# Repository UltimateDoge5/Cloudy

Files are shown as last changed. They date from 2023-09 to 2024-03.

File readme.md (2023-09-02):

# Cloudy

A weather station with a fronted UI and PHP backend was my first-ever web project. It has been 4 years since I finished it, and I've decided to do it again but with my current knowledge.

Another reason for this project is that I wanted to learn how to design schematics and PCBs.
You can see the (hopefully) live data on the [website](https://cloudy.pkozak.org).

## Hardware

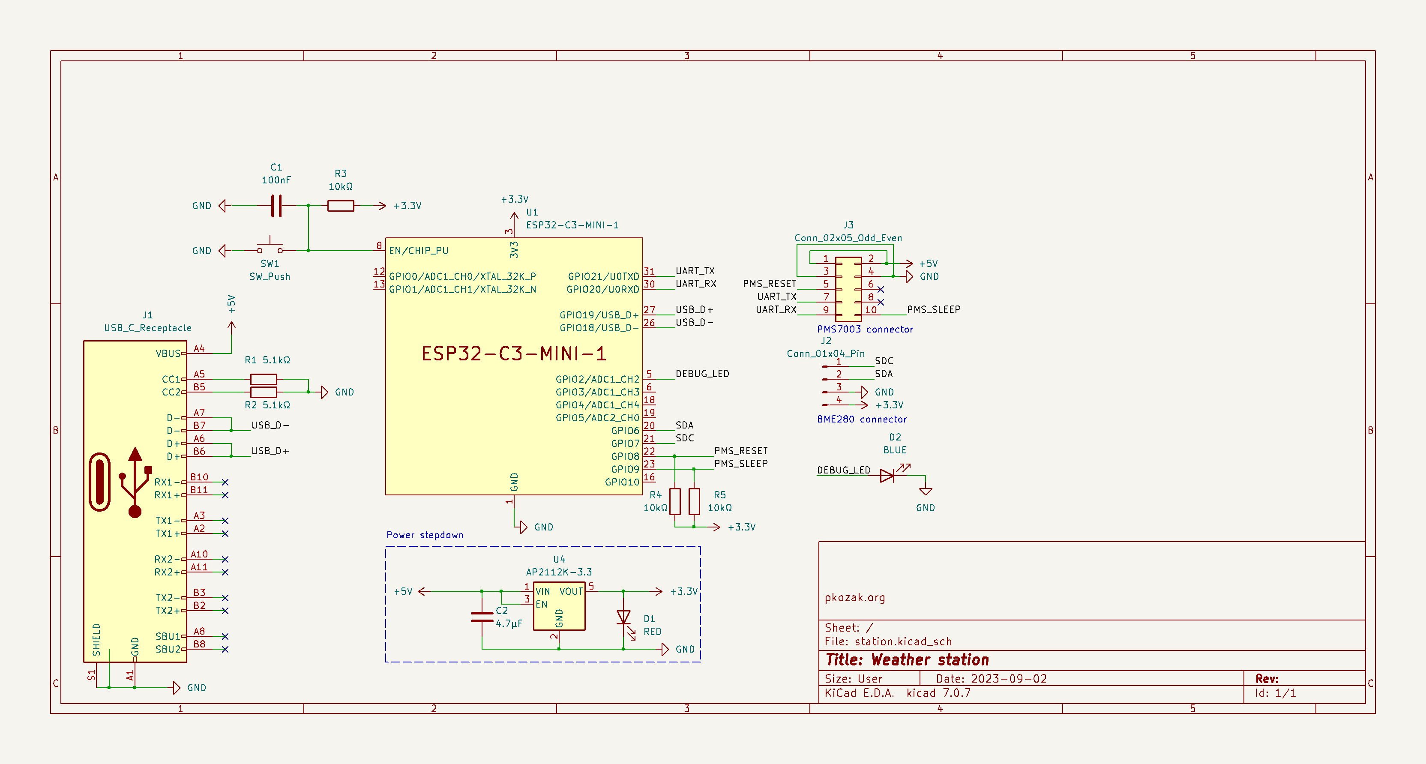
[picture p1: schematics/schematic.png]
Schematic of the weather station


The station uses a BME280 sensor to measure temperature, humidity and pressure. Besides uploading the data, it's also shown on a 0.96" OLED display (Not included in schematic).

The [schematics](/schematics/) and PCB use an ESP32-C3-MINI-N4, but because of the costs of manufacturing, assembly/stencil and
shipping, I've decided to assemble it on a breadboard with an ESP32-WROOM devkit.

The [schematics](/schematics/) also include a 3.3V voltage regulator, USB type C for power and programming, and a IDC header for a PMS7003 air quality sensor that I could integrate later if I'd like to.

As for the future sensors, aside from the PM2.5 sensor, I'd like to add a rain sensor and an anemometer.
The first one is cheap and easy to do, but the second one is not so much. Anemometers are expensive, and I don't have the tools to make one myself.
Even if I had one, I do not have an appropriate location to install it.

## Software

The software for the station is in the [driver folder](./driver). It's written in C++ and uses Arduino libraries. For the backend, I've decided to use Supabase, because of the REST database API and the real-time features which allowed an easy integration with the microcontroller.

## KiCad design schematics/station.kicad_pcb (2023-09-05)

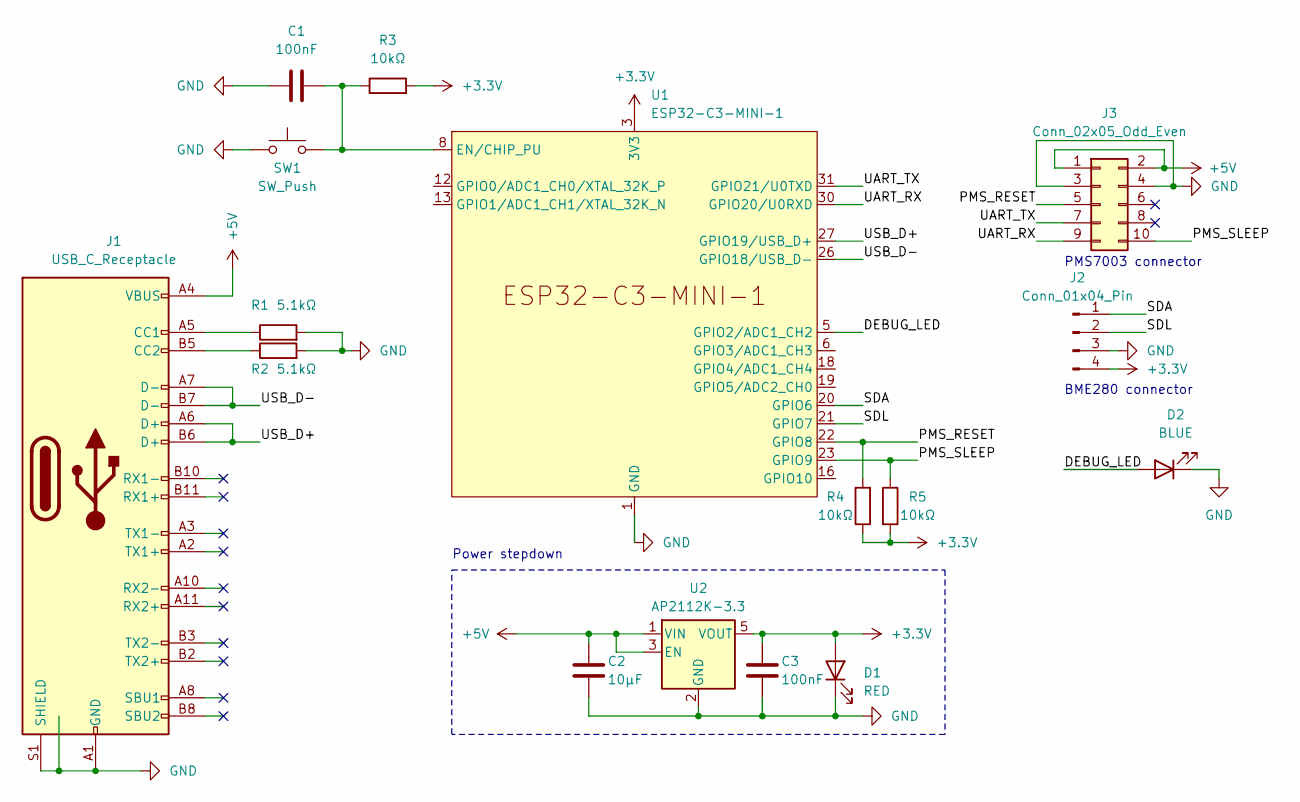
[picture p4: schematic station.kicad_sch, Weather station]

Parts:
C1, C3: 100nF; C_0805_2012Metric_Pad1.18x1.45mm_HandSolder
C2: 10µF; C_0805_2012Metric_Pad1.18x1.45mm_HandSolder
D1: RED; LED_0805_2012Metric_Pad1.15x1.40mm_HandSolder
D2: BLUE; LED_0805_2012Metric_Pad1.15x1.40mm_HandSolder
J1: USB_C_Receptacle; USB_C_Receptacle_Amphenol_12401610E4-2A
J2: Conn_01x04_Pin; PinHeader_1x04_P2.54mm_Vertical
J3: Conn_02x05_Odd_Even; IDC-Header_2x05_P2.54mm_Vertical
R1, R2: 5.1kΩ; R_1206_3216Metric
R3, R4, R5: 10kΩ; R_1206_3216Metric
SW1: SW_Push; SW_PUSH_6mm_H5mm
U1: ESP32-C3-MINI-1
U2: AP2112K-3.3; SOT-23-5

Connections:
+3.3V: C3.1, D1.2 (A), J2.4, R3.2, R4.1, R5.2, U1.3 (3V3), U2.5 (VOUT)
+5V: C2.1, J1.A4 (VBUS), J1.A9 (VBUS), J1.B4 (VBUS), J1.B9 (VBUS), J3.1, J3.2, U2.1 (VIN), U2.3 (EN)
/DEBUG_LED: D2.2 (A), U1.5 (GPIO2/ADC1_CH2)
/PMS_RESET: J3.5, R4.2, U1.22 (GPIO8)
/PMS_SLEEP: J3.10, R5.1, U1.23 (GPIO9)
/SDA: J2.1, U1.20 (GPIO6)
/SDL: J2.2, U1.21 (GPIO7)
/UART_RX: J3.9, U1.30 (GPIO20/U0RXD)
/UART_TX: J3.7, U1.31 (GPIO21/U0TXD)
/USB_D+: J1.A6 (D+), J1.B6 (D+), U1.27 (GPIO19/USB_D+)
/USB_D-: J1.A7 (D-), J1.B7 (D-), U1.26 (GPIO18/USB_D-)
GND: C1.1, C2.2, C3.2, D1.1 (K), D2.1 (K), J1.A1 (GND), J1.A12 (GND), J1.B1 (GND), J1.B12 (GND), J1.S1 (SHIELD), J2.3, J3.3, J3.4, R1.2, R2.2, SW1.1, U1.1 (GND), U1.2 (GND), U1.11 (GND), U1.14 (GND), U1.36 (GND), U1.37 (GND), U1.38 (GND), U1.39 (GND), U1.40 (GND), U1.41 (GND), U1.42 (GND), U1.43 (GND), U1.44 (GND), U1.45 (GND), U1.46 (GND), U1.47 (GND), U1.48 (GND), U1.49 (GND), U1.50 (GND), U1.51 (GND), U1.52 (GND), U1.53 (GND), U2.2 (GND)
unnamed: J1.A5 (CC1), R1.1
unnamed: J1.B5 (CC2), R2.1
unnamed: C1.2, R3.1, SW1.2, U1.8 (EN/CHIP_PU)

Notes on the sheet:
BME280 connector
Power stepdown
PMS7003 connector

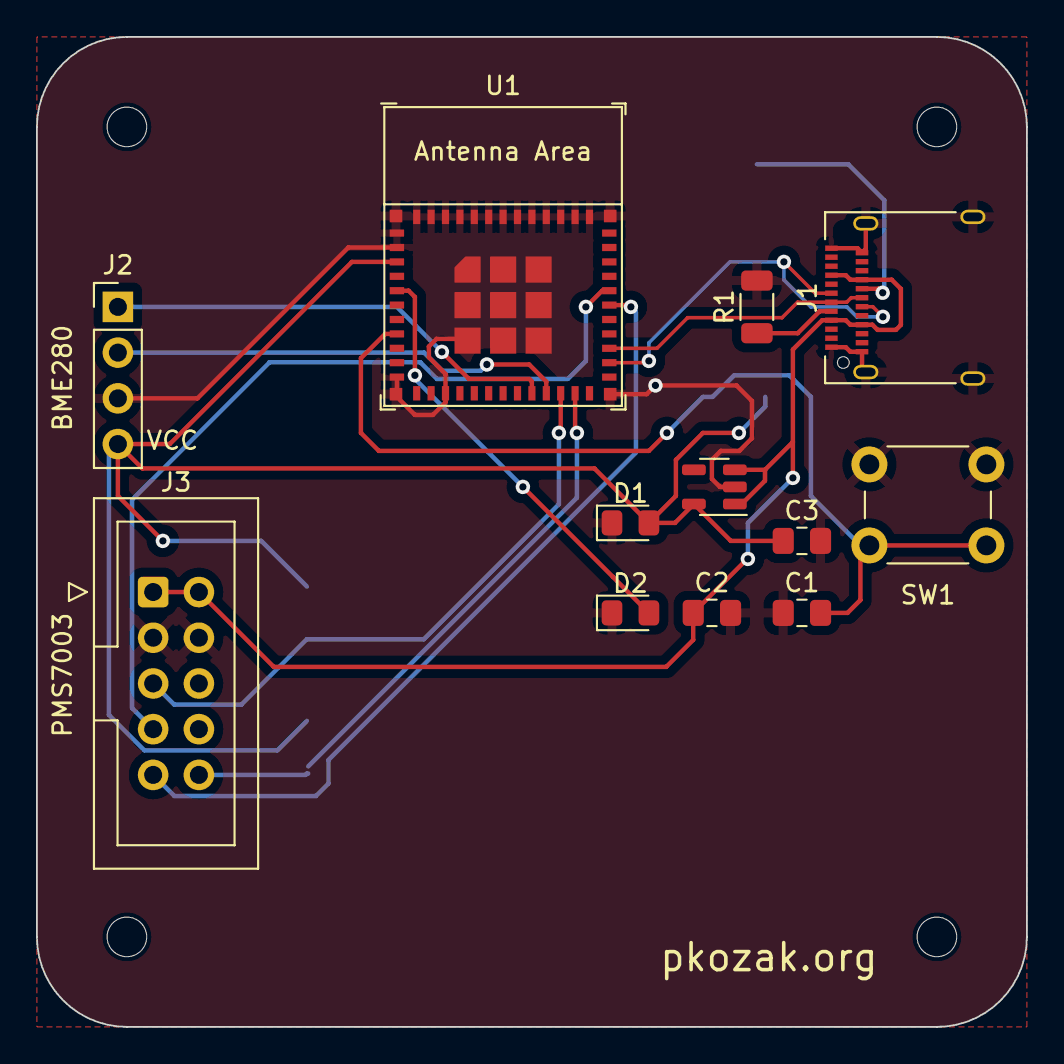
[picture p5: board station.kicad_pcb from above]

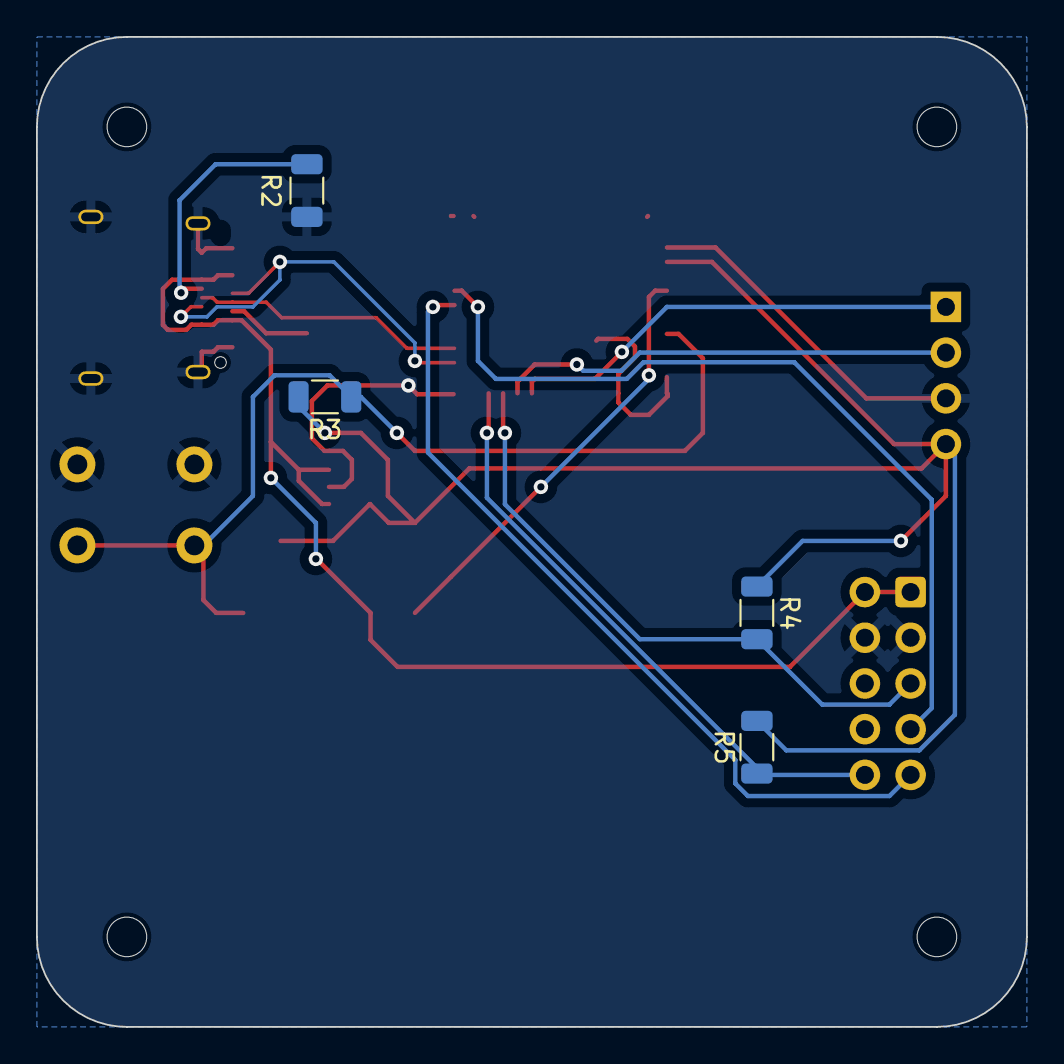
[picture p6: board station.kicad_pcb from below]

Board: 2 copper layers, 55.0 x 55.0 mm, 16 parts (4 on the bottom side), 15 nets.

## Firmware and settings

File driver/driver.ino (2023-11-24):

#include "time.h"
#include <Wire.h>
#include <WiFi.h>
#include <WiFiClientSecure.h>
#include <HTTPClient.h>
#include <Arduino_JSON.h>
#include <Adafruit_Sensor.h>
#include <Adafruit_BME280.h>
#include <Adafruit_GFX.h>
#include <Adafruit_SH110X.h>
#include <EEPROM.h>
#include "logo.h"
// Contains the WiFi credentials and the Supabase URL and key
#include "envs.h"

#define I2C_SDA 21
#define I2C_SCL 22
#define WAKEUP_PIN 4

#define i2c_Address 0x3c

#define SCREEN_WIDTH 128 // OLED display width, in pixels
#define SCREEN_HEIGHT 64 // OLED display height, in pixels
#define OLED_RESET 19

// Time between uploads to the database
#define DATABASE_INTERVAL 20000
#define SEALEVELPRESSURE_HPA (1013.25)

#define DEBUG_LED true  // Set to true to enable the debug LED
#define DEBUG_LED_PIN 2 // Onboard LED of the ESP32 dev board

#define INTEGER_LIMIT 2147483647

const char *ntpServer = "pool.ntp.org";
const long gmtOffset_sec = 3600;
const int daylightOffset_sec = 3600;

TaskHandle_t UploadTask;

TwoWire I2CWire = TwoWire(0);
Adafruit_SH1106G display = Adafruit_SH1106G(SCREEN_WIDTH, SCREEN_HEIGHT, &I2CWire, OLED_RESET);
Adafruit_BME280 bme;

String uploadError = "";

int screenTime = 0;

void setup()
{
  pinMode(WAKEUP_PIN, INPUT);
  pinMode(DEBUG_LED_PIN, OUTPUT);

  Serial.begin(115200);
  I2CWire.begin(I2C_SDA, I2C_SCL, 100000);

  delay(250);
  display.begin(i2c_Address, true);
  display.setTextSize(1);
  display.setTextColor(SH110X_WHITE);
  display.setCursor(0, 0);
  display.clearDisplay();
  display.drawBitmap((SCREEN_WIDTH - 32) / 2, (SCREEN_HEIGHT - 32) / 2, logo, 32, 32, SH110X_WHITE);
  display.setCursor((SCREEN_WIDTH - 32) / 2 - 16, (SCREEN_HEIGHT - 32) / 2 + 38);
  display.println("pkozak.org");
  display.display();
  delay(350);

  bool status = bme.begin(0x76, &I2CWire);
  if (!status)
  {
    Serial.println("Could not find the BME280 sensor!");
#ifdef DEBUG_LED
    digitalWrite(DEBUG_LED_PIN, HIGH);
#endif
    while (1)
    {
      display.clearDisplay();
      display.setCursor(0, 0);
      display.setTextSize(2);
      display.invertDisplay(false);
      display.println("No sensor!");
      display.setTextSize(1);
      display.println("No BME280 sensor.");
      display.println("Please check the wiring");
      display.display();
      delay(1500);
      display.clearDisplay();
      display.setCursor(0, 0);
      display.setTextSize(2);
      display.invertDisplay(true);
      display.println("No sensor!");
      display.setTextSize(1);
      display.println("No BME280 sensor.");
      display.println("Please check the wiring");
      display.display();
      delay(1500);
    }
  }

  EEPROM.writeInt(0x00, 0);
  EEPROM.commit();

  WiFi.begin(ssid, password);
  Serial.print("Connecting...");

  display.clearDisplay();
  display.setCursor(0, 0);
  display.println("Connecting to WiFi");
  display.display();

  while (WiFi.status() != WL_CONNECTED && WiFi.status() != WL_CONNECT_FAILED)
  {
    delay(500);
    Serial.print(".");
    display.print(".");
    display.display();
  }

  display.clearDisplay();
  display.setCursor(0, 0);
  if (WiFi.status() != WL_CONNECT_FAILED)
  {
    configTime(gmtOffset_sec, daylightOffset_sec, ntpServer);
    Serial.println("");
    Serial.print("Connected to WiFi\n");

    display.println("Connected to WiFi");
    display.display();

    xTaskCreatePinnedToCore(
        UploadData,   /* Task function. */
        "uploadData", /* name of task. */
        10000,        /* Stack size of task */
        NULL,         /* parameter of the task */
        1,            /* priority of the task */
        &UploadTask,  /* Task handle to keep track of created task */
        1);           /* pin task to core 1 */
  }
  else
  {
    Serial.println("");
    Serial.println("Connection failed\n");
    Serial.println("Working in offline mode");

    display.println("Connection failed");
    display.println("Working in offline mode");
    display.display();
  }
}

void loop()
{
  // After 10s of inactivity, display the screen saver
  if (screenTime >= 10000)
  {
    display.clearDisplay();
    while (digitalRead(WAKEUP_PIN) == LOW)
    {
      // Clear the screen and wait for the button to be pressed
    }
    screenTime = 0;
  }

  struct tm timeinfo;
  getLocalTime(&timeinfo);

  int temp = bme.readTemperature();
  int pressure = bme.readPressure() / 100.0F;
  int humidity = bme.readHumidity();

  display.clearDisplay();
  display.setCursor(0, 0);
  if (temp == INTEGER_LIMIT || pressure < 0) // Avoid displaying invalid data
  {
    display.setTextSize(2);
    display.println("Error while reading data");
    display.setTextSize(1);
    display.println("Please restart");
#ifdef DEBUG_LED
    digitalWrite(DEBUG_LED_PIN, HIGH);
#endif
  }
  else
  {
    display.println("Temp: " + String(temp) + " C");
    display.println("Pressure: " + String(pressure) + " hPa");
    display.println("Humidity: " + String(humidity) + "%");
    screenTime += 500;
  }

  if (WiFi.status() == WL_CONNECTED)
  {
    display.println("");
    display.println(&timeinfo, "%H:%M:%S");
  }
  else
  {
    display.setCursor(0, SCREEN_HEIGHT - 10);
    display.println("Offline");
  }

  if (uploadError != "")
  {
    display.setCursor(0, SCREEN_HEIGHT - 10);
    display.println(uploadError);
  }

  display.drawBitmap(SCREEN_WIDTH - 32, SCREEN_HEIGHT - 32, logo, 32, 32, SH110X_WHITE);
  display.display();

  delay(500);
}

void UploadData(void *pvParameters)
{
  while (1)
  {
    int time = millis();
    float temp = bme.readTemperature();
    int pressure = bme.readPressure() / 100.0F;
    if (temp == INTEGER_LIMIT || pressure < 0) // Avoid uploading invalid data
    {
      Serial.println("Error while reading data, skipping upload");
#ifdef DEBUG_LED
      digitalWrite(DEBUG_LED_PIN, HIGH);
#endif
      delay(DATABASE_INTERVAL);
      return;

      // Read restart count from eeprom
      int restarts = EEPROM.read(0x00);
      if (restarts == 3)
      {
        return;
      }

      EEPROM.writeInt(0x00, restarts + 1);
      EEPROM.commit();
      ESP.restart();
    }

    HTTPClient http;
    http.begin(SUPABASE_URL);
    http.addHeader("Content-Type", "application/json");
    http.addHeader("Authorization", String("Bearer ") + String(SUPABASE_KEY));
    http.addHeader("apikey", String(SUPABASE_KEY));

    JSONVar weather;

    weather["temperature"] = bme.readTemperature();
    weather["pressure"] = bme.readPressure() / 100.0F;
    weather["humidity"] = bme.readHumidity();

    int resp = http.POST(JSON.stringify(weather));
    if (resp != 201)
    {
      Serial.println("Error uploading data");
      Serial.println(http.errorToString(resp));
      Serial.println(http.getString());
      uploadError = "Error code " + String(resp);
#ifdef DEBUG_LED
      digitalWrite(DEBUG_LED_PIN, HIGH);
#endif
    }
    else
    {
      uploadError = "";
#ifdef DEBUG_LED
      digitalWrite(DEBUG_LED_PIN, LOW);
#endif
    }

    int diff = millis() - time;
    delay(DATABASE_INTERVAL - diff);
  }
}

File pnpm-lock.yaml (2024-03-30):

lockfileVersion: '6.0'

settings:
  autoInstallPeers: true
  excludeLinksFromLockfile: false

dependencies:
  '@headlessui/react':
    specifier: ^1.7.18
    version: 1.7.18(react-dom@18.2.0)(react@18.2.0)
  '@supabase/supabase-js':
    specifier: ^2.41.1
    version: 2.41.1
  '@types/node':
    specifier: 20.12.2
    version: 20.12.2
  '@types/react':
    specifier: 18.2.73
    version: 18.2.73
  '@types/react-dom':
    specifier: 18.2.23
    version: 18.2.23
  chart.js:
    specifier: ^4.4.2
    version: 4.4.2
  chartjs-adapter-dayjs-4:
    specifier: ^1.0.4
    version: 1.0.4(chart.js@4.4.2)(dayjs@1.11.10)
  dayjs:
    specifier: ^1.11.10
    version: 1.11.10
  eslint:
    specifier: 8.57.0
    version: 8.57.0
  eslint-config-next:
    specifier: 14.1.4
    version: 14.1.4(eslint@8.57.0)(typescript@5.4.3)
  next:
    specifier: 14.1.4
    version: 14.1.4(react-dom@18.2.0)(react@18.2.0)
  react:
    specifier: 18.2.0
    version: 18.2.0
  react-chartjs-2:
    specifier: ^5.2.0
    version: 5.2.0(chart.js@4.4.2)(react@18.2.0)
  react-dom:
    specifier: 18.2.0
    version: 18.2.0(react@18.2.0)
  typescript:
    specifier: 5.4.3
    version: 5.4.3

devDependencies:
  '@typescript-eslint/eslint-plugin':
    specifier: ^6.11.0
    version: 6.11.0(@typescript-eslint/parser@6.11.0)(eslint@8.57.0)(typescript@5.4.3)
  '@typescript-eslint/parser':
    specifier: ^6.11.0
    version: 6.11.0(eslint@8.57.0)(typescript@5.4.3)
  autoprefixer:
    specifier: ^10.4.19
    version: 10.4.19(postcss@8.4.38)
  postcss:
    specifier: ^8.4.38
    version: 8.4.38
  prettier:
    specifier: ^3.2.5
    version: 3.2.5
  prettier-plugin-tailwindcss:
    specifier: ^0.5.13
    version: 0.5.13(prettier@3.2.5)
  tailwindcss:
    specifier: ^3.4.3
    version: 3.4.3

packages:

  /@aashutoshrathi/word-wrap@1.2.6:
    resolution: {integrity: sha512-1Yjs2SvM8TflER/OD3cOjhWWOZb58A2t7wpE2S9XfBYTiIl+XFhQG2bjy4Pu1I+EAlCNUzRDYDdFwFYUKvXcIA==}
    engines: {node: '>=0.10.0'}

  /@alloc/quick-lru@5.2.0:
    resolution: {integrity: sha512-UrcABB+4bUrFABwbluTIBErXwvbsU/V7TZWfmbgJfbkwiBuziS9gxdODUyuiecfdGQ85jglMW6juS3+z5TsKLw==}
    engines: {node: '>=10'}
    dev: true

  /@babel/runtime@7.24.1:
    resolution: {integrity: sha512-+BIznRzyqBf+2wCTxcKE3wDjfGeCoVE61KSHGpkzqrLi8qxqFwBeUFyId2cxkTmm55fzDGnm0+yCxaxygrLUnQ==}
    engines: {node: '>=6.9.0'}
    dependencies:
      regenerator-runtime: 0.14.1
    dev: false

  /@eslint-community/eslint-utils@4.4.0(eslint@8.57.0):
    resolution: {integrity: sha512-1/sA4dwrzBAyeUoQ6oxahHKmrZvsnLCg4RfxW3ZFGGmQkSNQPFNLV9CUEFQP1x9EYXHTo5p6xdhZM1Ne9p/AfA==}
    engines: {node: ^12.22.0 || ^14.17.0 || >=16.0.0}
    peerDependencies:
      eslint: ^6.0.0 || ^7.0.0 || >=8.0.0
    dependencies:
      eslint: 8.57.0
      eslint-visitor-keys: 3.4.3

  /@eslint-community/regexpp@4.10.0:
    resolution: {integrity: sha512-Cu96Sd2By9mCNTx2iyKOmq10v22jUVQv0lQnlGNy16oE9589yE+QADPbrMGCkA51cKZSg3Pu/aTJVTGfL/qjUA==}
    engines: {node: ^12.0.0 || ^14.0.0 || >=16.0.0}

  /@eslint/eslintrc@2.1.4:
    resolution: {integrity: sha512-269Z39MS6wVJtsoUl10L60WdkhJVdPG24Q4eZTH3nnF6lpvSShEK3wQjDX9JRWAUPvPh7COouPpU9IrqaZFvtQ==}
    engines: {node: ^12.22.0 || ^14.17.0 || >=16.0.0}
    dependencies:
      ajv: 6.12.6
      debug: 4.3.4
      espree: 9.6.1
      globals: 13.24.0
      ignore: 5.3.1
      import-fresh: 3.3.0
      js-yaml: 4.1.0
      minimatch: 3.1.2
      strip-json-comments: 3.1.1
    transitivePeerDependencies:
      - supports-color

  /@eslint/js@8.57.0:
    resolution: {integrity: sha512-Ys+3g2TaW7gADOJzPt83SJtCDhMjndcDMFVQ/Tj9iA1BfJzFKD9mAUXT3OenpuPHbI6P/myECxRJrofUsDx/5g==}
    engines: {node: ^12.22.0 || ^14.17.0 || >=16.0.0}

  /@headlessui/react@1.7.18(react-dom@18.2.0)(react@18.2.0):
    resolution: {integrity: sha512-4i5DOrzwN4qSgNsL4Si61VMkUcWbcSKueUV7sFhpHzQcSShdlHENE5+QBntMSRvHt8NyoFO2AGG8si9lq+w4zQ==}
    engines: {node: '>=10'}
    peerDependencies:
      react: ^16 || ^17 || ^18
      react-dom: ^16 || ^17 || ^18
    dependencies:
      '@tanstack/react-virtual': 3.2.0(react-dom@18.2.0)(react@18.2.0)
      client-only: 0.0.1
      react: 18.2.0
      react-dom: 18.2.0(react@18.2.0)
    dev: false

  /@humanwhocodes/config-array@0.11.14:
    resolution: {integrity: sha512-3T8LkOmg45BV5FICb15QQMsyUSWrQ8AygVfC7ZG32zOalnqrilm018ZVCw0eapXux8FtA33q8PSRSstjee3jSg==}
    engines: {node: '>=10.10.0'}
    dependencies:
      '@humanwhocodes/object-schema': 2.0.2
      debug: 4.3.4
      minimatch: 3.1.2
    transitivePeerDependencies:
      - supports-color

  /@humanwhocodes/module-importer@1.0.1:
    resolution: {integrity: sha512-bxveV4V8v5Yb4ncFTT3rPSgZBOpCkjfK0y4oVVVJwIuDVBRMDXrPyXRL988i5ap9m9bnyEEjWfm5WkBmtffLfA==}
    engines: {node: '>=12.22'}

  /@humanwhocodes/object-schema@2.0.2:
    resolution: {integrity: sha512-6EwiSjwWYP7pTckG6I5eyFANjPhmPjUX9JRLUSfNPC7FX7zK9gyZAfUEaECL6ALTpGX5AjnBq3C9XmVWPitNpw==}
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

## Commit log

2023-08-22 Finished the offline driver
2023-08-22 Driver now uploads data to db
2023-08-22 Added invalid value checks
    Added invalid value checks and a screen saver to prevent burn-in.
    [driver.ino]
2023-08-23 Removed prisma
    Removed prisma and switched to pnpm
2023-08-27 Added dark mode support
    Added dark mode support and the debug led to the station.
2023-08-27 Improved responsivness
    Added additional data checks to the driver
2023-08-30 Added max and min temp display for current month
2023-09-02 Added the KiCad files
    [station.kicad_pcb, station.kicad_sch]
2023-09-02 Added another decoupling capacitor
    [station.kicad_pcb, station.kicad_sch]
2023-09-05 Some clarity changes and minor refactors
    [station.kicad_pcb, station.kicad_sch]
2023-11-24 Fixed a bug with temperatures lower than 1.0
    Fixed a bug where temperatures lower than 1.0 would not upload.
    [driver.ino, pnpm-lock.yaml]
